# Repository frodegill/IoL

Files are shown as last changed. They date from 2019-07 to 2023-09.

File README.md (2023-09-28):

# IoL
Internet Of Låve (english: Internet Of Barn, a play on the term Internet Of Things) is a system I've made for a colleague at Computas that also happens to have a farm.  
The systems consists of a Raspberry Pi server, a WiFi access point for local WiFi and a set of ESP8266 with custom shield reporting sensor values using MQTT over WiFi.  

The custom shield is used for these tasks:
* Outdoor temperature and humidity
* Indoor temperature and humidity
* Air duct temperature, humidity, air speed and air pressure
* Two temperature and humidity sensors to put into the grain

The goal of this project is to calculate when outside air blown indoors is drier than the air that is already indoor, and thus starting a fan running on cheap electricity would be enough to dry the grain instead of having the air dryer running on expensive diesel.

### pictures

Here is a picture of the barn full of grain. The air duct comes down from the ceiling and under the left side window. There are air vents crossing the room running from the left side air duct.  
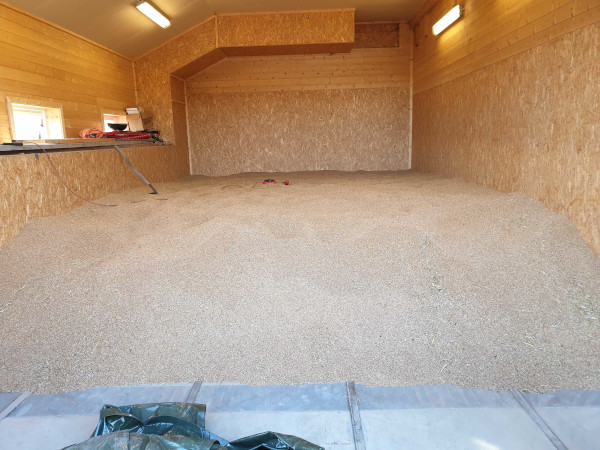
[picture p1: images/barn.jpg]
The barn full of grain
  

All sensor values are sent by MQTT to Mosquitto running on the Raspberry Pi. A local installation of Node-Red captures the values, massages them, and stores them in InfluxDB. A Grafana dashboard fetches data from InfluxDB and makes informative graphs. In the screenshot below you can see the period where the fan was manually turned on (thus creating wind speed and pressure difference in the air duct). This was immediately after the grain was harvested, so the results are admittedly better than usual, but you can see that the temperature and humidity in the grain will trend towards that in the air duct. As the outside humidity adjusted for indoor temperature is higher than the indoor humidity at the time of the screenshot, running the fan does not result in dryer grain and was only done for demonstration purposes.  
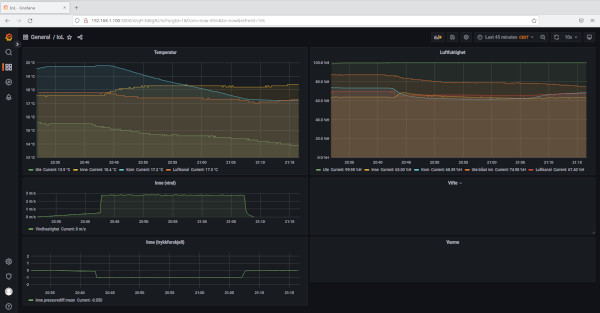
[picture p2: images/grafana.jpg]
Grafana dashboard


The barn does not have an internet connection, but the WiFi access point exposes Grafana running on the Raspberry Pi, and accessing it from a phone connected to the same WiFi network works like a charm.  
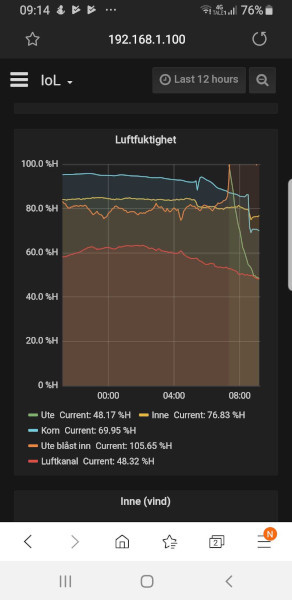
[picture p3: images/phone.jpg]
Grafana on small screen device


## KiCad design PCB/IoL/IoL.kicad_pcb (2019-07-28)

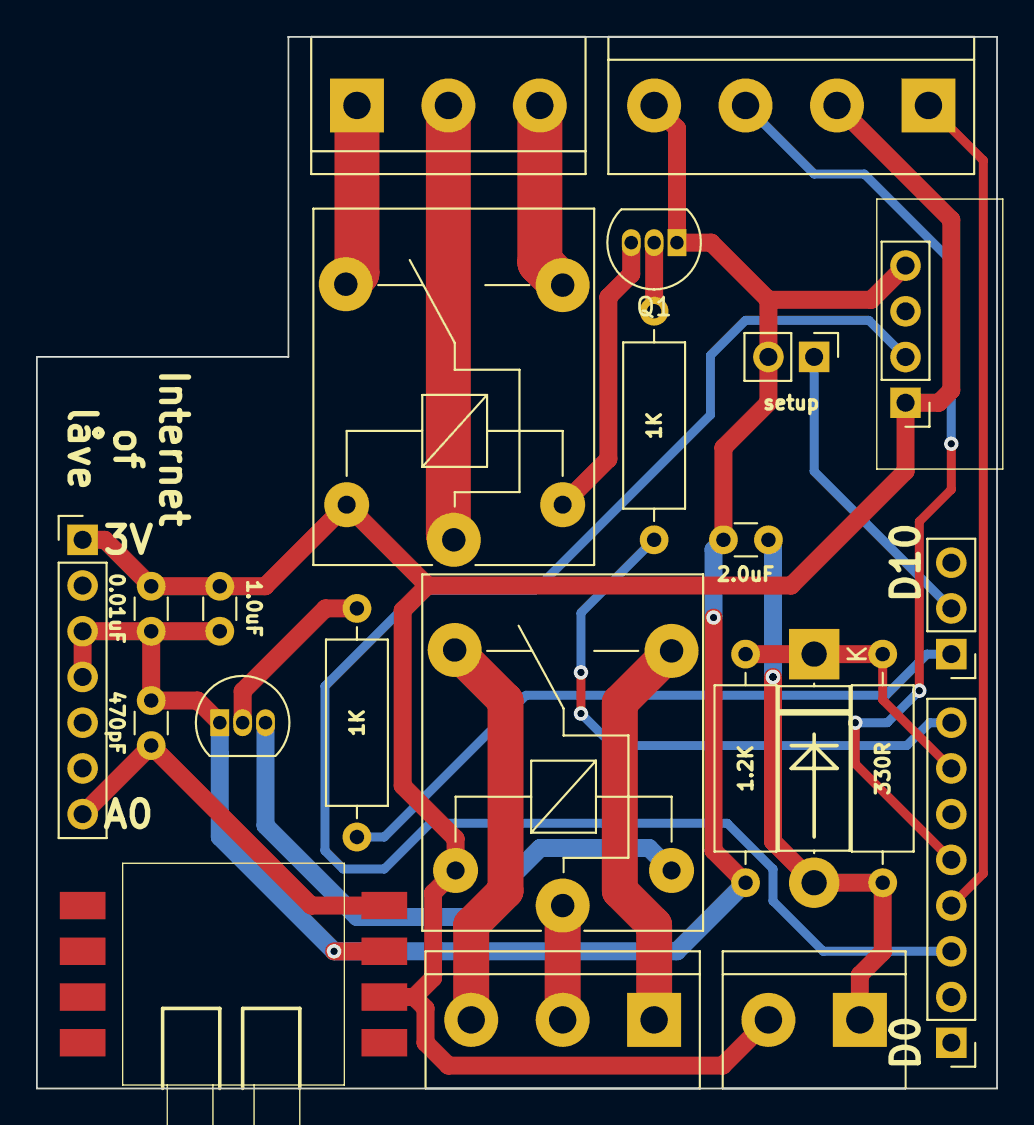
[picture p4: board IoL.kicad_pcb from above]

Board: 2 copper layers, 53.3 x 58.4 mm, 23 parts (0 on the bottom side), 21 nets.

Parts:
C1: 470pF; C_Disc_D3.0mm_W1.6mm_P2.50mm
C2: 1.0uF; C_Disc_D3.0mm_W1.6mm_P2.50mm
C3: 0.01uF; C_Disc_D3.0mm_W1.6mm_P2.50mm
C4: 2.0uF; C_Disc_D3.0mm_W1.6mm_P2.50mm
D1: D; D_5W_P12.70mm_Horizontal
J1, J9: Conn_01x03_Male; TerminalBlock_bornier-3_P5.08mm
J2: Conn_01x07_Male; PinHeader_1x07_P2.54mm_Vertical
J3: Conn_01x04_Male; TerminalBlock_bornier-4_P5.08mm
J5: Conn_01x02_Male; TerminalBlock_bornier-2_P5.08mm
J6: Conn_01x02_Male; PinHeader_1x02_P2.54mm_Vertical
J7: Conn_01x03_Male; PinHeader_1x03_P2.54mm_Vertical
J8: Conn_01x08_Male; PinHeader_1x08_P2.54mm_Vertical
K1, K2: SANYOU_SRD_Form_C; Relay_SPDT_SANYOU_SRD_Series_Form_C
Q1, Q2: BC337; TO-92_Inline
R1: 1.2K; R_Axial_DIN0309_L9.0mm_D3.2mm_P12.70mm_Horizontal
R2: 330R; R_Axial_DIN0309_L9.0mm_D3.2mm_P12.70mm_Horizontal
R3, R4: 1K; R_Axial_DIN0309_L9.0mm_D3.2mm_P12.70mm_Horizontal
U1: MP3V5004G
U2: AM2302

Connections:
+3V3: C2.1, C3.1, J2.1, J3.2, J5.2, K1.5, K2.5, U1.2, U2.1
GND: C1.2, C2.2, C3.2, C4.2, J2.3, J2.4, J3.4, J6.2, Q1.1, Q2.1, R1.2, U1.3, U2.4
unnamed: C1.1, J2.7, U1.4
unnamed: C4.1, D1.2, J5.1, R2.2
unnamed: D1.1, J8.7, R1.1, R2.1
unnamed: J1.1, K1.4
unnamed: J1.2, K1.1
unnamed: J1.3, K1.3
unnamed: J3.1, J8.4
unnamed: J3.3, J8.5
unnamed: J6.1, J7.2
unnamed: J7.1, R3.1
unnamed: J8.3, U2.2
unnamed: J8.8, R4.1
unnamed: J9.1, K2.3
unnamed: J9.2, K2.1
unnamed: J9.3, K2.4
unnamed: K1.2, Q1.3
unnamed: K2.2, Q2.3
unnamed: Q1.2, R4.2
unnamed: Q2.2, R3.2

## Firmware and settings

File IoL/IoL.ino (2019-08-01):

/*
 * Internet Of Låve
 * 
 * Measure and display Temperature and Humidity (AM2302 DHT22) and Wind Speed (MPXV7002DP), 
 * and provide these values to a Munin plugin.
 * 
 * Running on a WeMos D1 WiFi board.
 */

#include <DHTesp.h>
#include <DNSServer.h>
#include <EEPROM.h>
#include <ESP8266WiFi.h>
#include <ESP8266WebServer.h>
#include <PubSubClient.h>
#include "SHT21.h"
#include <Ticker.h>

static const char* SETUP_SSID = "sensor-setup";
static const byte  EEPROM_INITIALIZED_MARKER = 0xF1; //Just a magic number

static const uint8_t DHT_TEMP_HUMIDITY_SENSOR         = 1<<0;
static const uint8_t SHT_TEMP_HUMIDITY_SENSOR         = 1<<1;
static const uint8_t PRESSURE_DIFF_SENSOR             = 1<<2;
static const uint8_t WINDSPEED_SENSOR                 = 1<<3;
static const uint8_t FAN_RELAY                        = 1<<4;
static const uint8_t THERMOSTAT_RELAY                 = 1<<5;


#define I_PRESSURE_DIFF_PIN            (A0) //Max 3.3V

#define O_SHT_SYNC_PIN                 (D3) //SCL
#define I_SHT_DATA_PIN                 (D4) //SDA
#define I_DHT_PIN                      (D2)
#define I_SETUP_MODE_PIN               (D9) //built-in LED
#define I_WINDSPEED_PIN                (D6)
#define O_FAN_RELAY_TRIGGER_PIN        (D7)
#define O_THERMOSTAT_RELAY_TRIGGER_PIN (D8)

#define DELAY_BETWEEN_ACTIVE_SENSORS   (25) //ms between reading different sensors
#define SENSOR_READ_DELAY_TIME         (10*1000)  //ms min. time between sensor reading cycle
#define MQTT_PUBLISH_INTERVAL          (5*1000) //ms min. time between publishing sensor values to MQTT server

static const float WINDSPEED_TRAVEL_DISTANCE = 0.2262; //meter pr rotation

#define DHT_MODEL (DHTesp::AM2302)


enum DEBUG_MODE
{
  DEBUG_NONE,
  DEBUG_SERIAL,
  DEBUG_MQTT
} debug_mode = DEBUG_SERIAL;
#define MQTT_DEBUG_TOPIC "debug"

enum State
{
  SETUP_MODE,
  READ_DHT_SENSOR,
  READ_SHT_SENSOR,
  READ_PRESSURE_DIFF_SENSOR
};


DHTesp dht;
SHT21 sht;

ESP8266WebServer server(80);

WiFiClient esp_client;
PubSubClient mqtt_client(esp_client);
long last_mqtt_publish_time = 0L;

//For SETUP_SSID AP
DNSServer dnsServer;
static const byte DNS_PORT = 53;
IPAddress apIP(192, 168, 4, 1);

Ticker ticker;

volatile State state;

#define MAX_SSID_LENGTH            (32)
#define MAX_PASSWORD_LENGTH        (64)
#define MAX_ACTIVE_SENSORS_LENGTH   (1)
#define MAX_MQTT_SERVERNAME_LENGTH (64)
#define MAX_MQTT_SENSORID_LENGTH    (8)
#define MAX_MQTT_USERNAME_LENGTH   (32)
#define MAX_MQTT_PASSWORD_LENGTH   (32)

char ssid_param[MAX_SSID_LENGTH+1];
char password_param[MAX_PASSWORD_LENGTH+1];
char mqtt_servername_param[MAX_MQTT_SERVERNAME_LENGTH+1];
char mqtt_sensorid_param[MAX_MQTT_SENSORID_LENGTH+1];
char mqtt_username_param[MAX_MQTT_USERNAME_LENGTH+1];
char mqtt_password_param[MAX_MQTT_PASSWORD_LENGTH+1];
bool mqtt_enabled;
uint8_t active_sensors_param = 0;

volatile bool should_read_dht_temp_sensor = false;
float dht_tempsensor_value, published_dht_tempsensor_value;
float dht_humiditysensor_value, published_dht_humiditysensor_value;

volatile bool should_read_sht_temp_sensor = false;
float sht_tempsensor_value, published_sht_tempsensor_value;
float sht_humiditysensor_value, published_sht_humiditysensor_value;

volatile float pressure_diff_value, published_pressure_diff_value = -999.9f;

volatile unsigned long windspeed_start_time;
volatile unsigned int windspeed_count;
float published_windspeed = -999.9f;

volatile bool debug_enabled = false; // Internal, to keep track of Serial status

//Forward define
bool connectMQTT();


void enableDebug()
{
  if (!debug_enabled)
  {
    debug_enabled = true;
    if (debug_mode==DEBUG_SERIAL)
    {
      Serial.begin(9600);
    }
  }
}

void disableDebug()
{
  if (debug_enabled)
  {
    debug_enabled = false;
    if (debug_mode==DEBUG_SERIAL)
    {
      Serial.flush();
      Serial.end();
    }
  }
}

void printDebug(const char* msg)
{
  if (debug_enabled && msg)
  {
    if (debug_mode==DEBUG_SERIAL)
    {
      Serial.println(msg);
    }
    else if (debug_mode==DEBUG_MQTT && mqtt_enabled)
    {
      if (connectMQTT())
      {
        Serial.println((String("MQTT publish returned ") + String(mqtt_client.publish((String(mqtt_sensorid_param)+F(MQTT_DEBUG_TOPIC)).c_str(), msg)?"true":"false")).c_str());
      }
      else
      {
        Serial.println("Debug failed - MQTT is not connected");
      }
    }
  }
}

void ICACHE_RAM_ATTR windspeedInterruptHandler()
{
  if (0 == windspeed_count)
  {
    windspeed_start_time = millis();
  }
  windspeed_count++;
}

float getWindspeed() // m/s
{
  if (0 == windspeed_count)
  {
    return 0.0f;
  }

  unsigned long current_time = millis();
  if (current_time < windspeed_start_time)
  {
    return 0.0f;
  }

  float windspeed = (windspeed_count*WINDSPEED_TRAVEL_DISTANCE) / (current_time-windspeed_start_time); // meter/ms
  windspeed_count = 0;
  return windspeed*1000.0f; // meter/s
}

void onTick()
{
  switch(state)
  {
    case READ_DHT_SENSOR:
      {
        if (active_sensors_param & DHT_TEMP_HUMIDITY_SENSOR)
        {
          should_read_dht_temp_sensor = true;
        }

        state = READ_SHT_SENSOR;
        ticker.attach_ms(DELAY_BETWEEN_ACTIVE_SENSORS, onTick);
        break;  
      }

    case READ_SHT_SENSOR:
      {
        if (active_sensors_param & SHT_TEMP_HUMIDITY_SENSOR)
        {
          should_read_sht_temp_sensor = true;
        }
        
        state = READ_PRESSURE_DIFF_SENSOR;
        ticker.attach_ms(DELAY_BETWEEN_ACTIVE_SENSORS, onTick);
        break;
      }
    
    case READ_PRESSURE_DIFF_SENSOR:
      {
        if (active_sensors_param & PRESSURE_DIFF_SENSOR)
        {
          pressure_diff_value = max(0, min(1023, analogRead(I_PRESSURE_DIFF_PIN))) * 5.0f / 1023.0f -2.5f;
          printDebug((String("reading pressure diff value ")+String(pressure_diff_value, 2)).c_str());
        }
        
        state = READ_DHT_SENSOR;
        ticker.attach_ms(SENSOR_READ_DELAY_TIME, onTick);
        break;
      }
    
    default: break;
  }
}

void readPersistentString(char* s, int max_length, int& adr)
{
  int i = 0;
  byte c;
  do
  {
    c = EEPROM.read(adr++);
    if (i<max_length)
    {
      s[i++] = static_cast<char>(c);
    }
  } while (c!=0);
  s[i] = 0;
}

void readPersistentByte(uint8_t& b, int& adr)
{
  b = EEPROM.read(adr++);
}

void readPersistentParams()
{
  int adr = 0;
  if (EEPROM_INITIALIZED_MARKER != EEPROM.read(adr++))
  {
    ssid_param[0] = 0;
    password_param[0] = 0;
    mqtt_servername_param[0] = 0;
    mqtt_sensorid_param[0] = 0;
    mqtt_username_param[0] = 0;
    mqtt_password_param[0] = 0;
    active_sensors_param = 0;
  }
  else
  {
    readPersistentString(ssid_param, MAX_SSID_LENGTH, adr);
    readPersistentString(password_param, MAX_PASSWORD_LENGTH, adr);
    readPersistentByte(active_sensors_param, adr);
    readPersistentString(mqtt_servername_param, MAX_MQTT_SERVERNAME_LENGTH, adr);
    readPersistentString(mqtt_sensorid_param, MAX_MQTT_SENSORID_LENGTH, adr);
    readPersistentString(mqtt_username_param, MAX_MQTT_USERNAME_LENGTH, adr);
    readPersistentString(mqtt_password_param, MAX_MQTT_PASSWORD_LENGTH, adr);
  }
}

void writePersistentString(const char* s, size_t max_length, int& adr)
{
  for (int i=0; i<min(strlen(s), max_length); i++)
  {
    EEPROM.write(adr++, s[i]);
  }
  EEPROM.write(adr++, 0);
}

void writePersistentByte(uint8_t b, int& adr)
{
  EEPROM.write(adr++, b);
}

void writePersistentParams(const char* ssid, const char* password, uint8_t active_sensors)
{
  int adr = 0;
  EEPROM.write(adr++, EEPROM_INITIALIZED_MARKER);
  writePersistentString(ssid, MAX_SSID_LENGTH, adr);
  writePersistentString(password, MAX_PASSWORD_LENGTH, adr);
  writePersistentByte(active_sensors, adr);
  writePersistentString(mqtt_servername_param, MAX_MQTT_SERVERNAME_LENGTH, adr);
  writePersistentString(mqtt_sensorid_param, MAX_MQTT_SENSORID_LENGTH, adr);
  writePersistentString(mqtt_username_param, MAX_MQTT_USERNAME_LENGTH, adr);
  writePersistentString(mqtt_password_param, MAX_MQTT_PASSWORD_LENGTH, adr);
  EEPROM.commit();
}

void activateHeater(bool activate)
{
  if (active_sensors_param & THERMOSTAT_RELAY)
  {
    digitalWrite(O_THERMOSTAT_RELAY_TRIGGER_PIN, activate ? HIGH : LOW);
  }
}

void activateFan(bool activate)
{
  if (active_sensors_param & FAN_RELAY)
  {
    digitalWrite(O_FAN_RELAY_TRIGGER_PIN, activate ? HIGH : LOW);
  }
}

void handleNotFound()
{
  server.send(404, F("text/plain"), F("Page Not Found\n"));
}

void handleSetupRoot()
{
  if (server.hasArg("ssid") || server.hasArg("password")
      || server.hasArg("mqtt_server") || server.hasArg("mqtt_id") || server.hasArg("mqtt_username") || server.hasArg("mqtt_password")
      || server.hasArg("sensor0") || server.hasArg("sensor1") || server.hasArg("sensor2") || server.hasArg("sensor3")
      || server.hasArg("sensor4") || server.hasArg("sensor5") || server.hasArg("sensor6") || server.hasArg("sensor7"))
  {
    if (server.hasArg("ssid"))
    {
      strncpy(ssid_param, server.arg("ssid").c_str(), MAX_SSID_LENGTH);
      ssid_param[MAX_SSID_LENGTH] = 0;
    }
    
    if (server.hasArg("password") && !server.arg("password").equals(F("password")))
    {
      strncpy(password_param, server.arg("password").c_str(), MAX_PASSWORD_LENGTH);
      password_param[MAX_PASSWORD_LENGTH] = 0;
    }

    if (server.hasArg("mqtt_server"))
    {
      strncpy(mqtt_servername_param, server.arg("mqtt_server").c_str(), MAX_MQTT_SERVERNAME_LENGTH);
      mqtt_servername_param[MAX_MQTT_SERVERNAME_LENGTH] = 0;
    }
    if (server.hasArg("mqtt_id"))
    {
      strncpy(mqtt_sensorid_param, server.arg("mqtt_id").c_str(), MAX_MQTT_SENSORID_LENGTH);
      mqtt_sensorid_param[MAX_MQTT_SENSORID_LENGTH] = 0;
    }
    if (server.hasArg("mqtt_username"))
    {
      strncpy(mqtt_username_param, server.arg("mqtt_username").c_str(), MAX_MQTT_USERNAME_LENGTH);
      mqtt_username_param[MAX_MQTT_USERNAME_LENGTH] = 0;
    }
    if (server.hasArg("mqtt_password") && !server.arg("mqtt_password").equals(F("mqtt_password")))
    {
      strncpy(mqtt_password_param, server.arg("mqtt_password").c_str(), MAX_MQTT_PASSWORD_LENGTH);
      mqtt_password_param[MAX_MQTT_PASSWORD_LENGTH] = 0;
    }

    active_sensors_param = 0;
    if (server.hasArg("sensor0")) {active_sensors_param |= 1<<0;}
    if (server.hasArg("sensor1")) {active_sensors_param |= 1<<1;}
    if (server.hasArg("sensor2")) {active_sensors_param |= 1<<2;}
    if (server.hasArg("sensor3")) {active_sensors_param |= 1<<3;}
    if (server.hasArg("sensor4")) {active_sensors_param |= 1<<4;}
    if (server.hasArg("sensor5")) {active_sensors_param |= 1<<5;}
    if (server.hasArg("sensor6")) {active_sensors_param |= 1<<6;}
    if (server.hasArg("sensor7")) {active_sensors_param |= 1<<7;}

    writePersistentParams(ssid_param, password_param, active_sensors_param);

    server.send(200, F("text/plain"), F("Settings saved"));
  }
  else
  {
    readPersistentParams();

    String body = F("<!doctype html>"\
                    "<html lang=\"en\">"\
                    "<head>"\
                     "<meta charset=\"utf-8\">"\
                     "<title>Setup</title>"\
                     "<style>"\
                      "form {margin: 0.5em;}"\
                      "input {margin: 0.2em;}"\
                     "</style>"\
                    "</head>"\
                    "<body>"\
                     "<form method=\"post\">"\
                      "SSID:<input type=\"text\" name=\"ssid\" required maxlength=\"");
    body += String(MAX_SSID_LENGTH);
    body += F("\" autofocus value=\"");
    body += ssid_param;
    body += F("\"/><br/>"\
              "Password:<input type=\"password\" name=\"password\" maxlength=\"");
    body += String(MAX_PASSWORD_LENGTH);
    body += F("\" value=\"password\"/><br/><hr/>"\
              "MQTT server:<input type=\"text\" name=\"mqtt_server\" maxlength=\"");
    body += String(MAX_MQTT_SERVERNAME_LENGTH);
    body += F("\" value=\"");
    body += mqtt_servername_param;
    body += F("\"/><br/>"\
              "MQTT sensor id:<input type=\"text\" name=\"mqtt_id\" maxlength=\"");
    body += String(MAX_MQTT_SENSORID_LENGTH);
    body += F("\" value=\"");
    body += mqtt_sensorid_param;
    body += F("\"/><br/>"\
              "MQTT username:<input type=\"text\" name=\"mqtt_username\" maxlength=\"");
    body += String(MAX_MQTT_USERNAME_LENGTH);
    body += F("\" value=\"");
    body += mqtt_username_param;
    body += F("\"/><br/>"\
              "MQTT password:<input type=\"password\" name=\"mqtt_password\" maxlength=\"");
    body += String(MAX_MQTT_PASSWORD_LENGTH);
    body += F("\" value=\"password\"/><br/><hr/>"\
              "Internal temp/humidity sensor: <input type=\"checkbox\" name=\"sensor0\"");
    if (active_sensors_param&DHT_TEMP_HUMIDITY_SENSOR)
      body += F(" checked");

    body += F("/><br/>External temp sensor: <input type=\"checkbox\" name=\"sensor1\"");
    if (active_sensors_param&SHT_TEMP_HUMIDITY_SENSOR)
      body += F(" checked");
    
    body += F("/><br/>Pressure diff. sensor: <input type=\"checkbox\" name=\"sensor2\"");
    if (active_sensors_param&PRESSURE_DIFF_SENSOR)
      body += F(" checked");
    
    body += F("/><br/>Windspeed sensor: <input type=\"checkbox\" name=\"sensor3\"");
    if (active_sensors_param&WINDSPEED_SENSOR)
      body += F(" checked");
    
    body += F("/><br/>Fan relay: <input type=\"checkbox\" name=\"sensor4\"");
    if (active_sensors_param&FAN_RELAY)
      body += F(" checked");
    
    body += F("/><br/>Heater thermostat plug: <input type=\"checkbox\" name=\"sensor5\"");
    if (active_sensors_param&THERMOSTAT_RELAY)
      body += F(" checked");
    
    body += F("/><br/>"\
              "<input type=\"submit\" value=\"Submit\"/>"\
              "</form>"\
             "</body>"\
             "</html>");
    server.send(200, F("text/html"), body);
  }
}

void mqttCallback(char* topic, byte* payload, unsigned int length)
{
  int mqtt_sensorid_param_length = strlen(mqtt_sensorid_param);
  if (0 != strncmp(mqtt_sensorid_param, topic, mqtt_sensorid_param_length))
  {
    return;
  }

  printDebug((String("mqttCallback: ")+String(topic)+String(" value ")+String(reinterpret_cast<const char*>(payload))).c_str());
  const char* key = topic + mqtt_sensorid_param_length;

  if (0 == strcmp("Heater", key))
  {
    activateHeater(0 == strcmp("on", reinterpret_cast<const char*>(payload)));
  }
  else if (0 == strcmp("Fan", key))
  {
    activateFan(0 == strcmp("on", reinterpret_cast<const char*>(payload)));
  }
}

void publishMQTTValue(const String& topic, const String& msg)
{
  if (mqtt_enabled && connectMQTT())
  {
    bool ret = mqtt_client.publish((String(mqtt_sensorid_param)+topic).c_str(), msg.c_str(), true);
    printDebug((String("publishMQTTValue topic=")+String(mqtt_sensorid_param)+topic+String(" msg=")+msg+String(" returned ")+String(ret?"true":"false")).c_str());
  }
}

void publishMQTTValue(const String& topic, float value)
{
  publishMQTTValue(topic, String(value, 4));
}

void publishMQTTValues()
{
  if (!mqtt_enabled)
    return;

  if (active_sensors_param&DHT_TEMP_HUMIDITY_SENSOR)
  {
    if (dht_tempsensor_value!=published_dht_tempsensor_value)
    {
      publishMQTTValue(F("DHT22T"), dht_tempsensor_value);
      published_dht_tempsensor_value = dht_tempsensor_value;
    }
    if (dht_humiditysensor_value!=published_dht_humiditysensor_value)
    {
      publishMQTTValue(F("DHT22H"), dht_humiditysensor_value);
      published_dht_humiditysensor_value = dht_humiditysensor_value;
    }
  }

  if (active_sensors_param&SHT_TEMP_HUMIDITY_SENSOR)
  {
    if (sht_tempsensor_value!=published_sht_tempsensor_value)
    {
      publishMQTTValue(F("SHT2XT"), sht_tempsensor_value);
      published_sht_tempsensor_value = sht_tempsensor_value;
    }
    if (sht_humiditysensor_value!=published_sht_humiditysensor_value)
    {
      publishMQTTValue(F("SHT2XH"), sht_humiditysensor_value);
      published_sht_humiditysensor_value = sht_humiditysensor_value;
    }
  }

  if (active_sensors_param&PRESSURE_DIFF_SENSOR)
  {
    if (pressure_diff_value!=published_pressure_diff_value)
    {
      publishMQTTValue(F("Pressure"), pressure_diff_value);
      published_pressure_diff_value = pressure_diff_value;
    }
  }
  
  if (active_sensors_param&WINDSPEED_SENSOR)
  {
    float windspeed = getWindspeed();
    printDebug((String("reading wind speed value ")+String(windspeed, 2)).c_str());
    if (windspeed!=published_windspeed)
    {
      publishMQTTValue(F("Wind"), windspeed);
      published_windspeed = windspeed;
    }
  }
}

bool connectMQTT()
{
  byte i = 0;
  while (i++<10 && mqtt_enabled && !mqtt_client.connected())
  {
    if (mqtt_client.connect(mqtt_sensorid_param, mqtt_username_param, mqtt_password_param))
    {
      printDebug("MQTT connected");

      if (active_sensors_param & THERMOSTAT_RELAY)
      {
        mqtt_client.subscribe((String(mqtt_sensorid_param)+F("Heater")).c_str());
      }
      
      if (active_sensors_param & FAN_RELAY)
      {
        mqtt_client.subscribe((String(mqtt_sensorid_param)+F("Fan")).c_str());
      }
      
      printDebug("MQTT topics subscribed");
    }
    else
    {
      printDebug("MQTT waiting for reconnect");
      // Wait 3 seconds before retrying
      delay(3000);
    }
  }
  return mqtt_client.connected();
}

void setup()
{
  enableDebug();

  EEPROM.begin(1 + MAX_SSID_LENGTH+1 + MAX_PASSWORD_LENGTH+1 + MAX_ACTIVE_SENSORS_LENGTH + MAX_MQTT_SERVERNAME_LENGTH+1 + MAX_MQTT_SENSORID_LENGTH+1 + MAX_MQTT_USERNAME_LENGTH+1 + MAX_MQTT_PASSWORD_LENGTH+1);

  pinMode(I_SETUP_MODE_PIN, INPUT_PULLUP);
  delay(100);

  if (/*true ||*/ LOW == digitalRead(I_SETUP_MODE_PIN))
  {
    printDebug("Mode:Setup");

    mqtt_enabled = false;
    state = SETUP_MODE;
    WiFi.softAP(SETUP_SSID);
    dnsServer.start(DNS_PORT, "*", apIP);

    server.on("/", handleSetupRoot);
    server.onNotFound(handleNotFound);
    server.begin();
  }
  else
  {
    printDebug("Mode:Normal");

    dht.setup(I_DHT_PIN, DHTesp::AM2302);
    sht.begin(/*I_SHT_DATA_PIN, O_SHT_SYNC_PIN*/);

    pinMode(O_FAN_RELAY_TRIGGER_PIN, OUTPUT);
    activateFan(false);

    pinMode(O_THERMOSTAT_RELAY_TRIGGER_PIN, OUTPUT);
    activateHeater(false);

    readPersistentParams();
    mqtt_enabled = mqtt_servername_param && *mqtt_servername_param;
    
    printDebug("Connecting to WiFi");
    WiFi.mode(WIFI_STA);
    WiFi.begin(ssid_param, password_param);
    while (WiFi.status() != WL_CONNECTED)
    {
      delay(500);
    }
    printDebug("WiFi connected");

    if (mqtt_enabled)
    {
      printDebug("Enabling MQTT");
      mqtt_client.setServer(mqtt_servername_param, 1883);
      mqtt_client.setCallback(mqttCallback);
      connectMQTT();
    }

    should_read_dht_temp_sensor = false;
    dht_tempsensor_value = dht_humiditysensor_value = 0.0f;

    should_read_sht_temp_sensor = false;
    sht_tempsensor_value = 0.0f;
    sht_humiditysensor_value = 0.0f;
    pressure_diff_value = 0.0f;

    state = READ_DHT_SENSOR;
    onTick();

    if (active_sensors_param && WINDSPEED_SENSOR)
    {
      windspeed_start_time = 0;
      windspeed_count = 0;
      attachInterrupt(digitalPinToInterrupt(I_WINDSPEED_PIN), windspeedInterruptHandler, RISING);
    }

    //Notify MQTT that relays have been turned off
    if (active_sensors_param & THERMOSTAT_RELAY)
    {
      publishMQTTValue("Heater", "off");
    }
    if (active_sensors_param & FAN_RELAY)
    {
      publishMQTTValue("Fan", "off");
    }
  }
}

void loop()
{
  if (state == SETUP_MODE)
  {
    dnsServer.processNextRequest(); //Route everything to 192.168.4.1
    server.handleClient(); //WebServer
  }
  else
  {
    if (mqtt_enabled && connectMQTT())
    {
      mqtt_client.loop();
    
      long now = millis();
      if ((now - last_mqtt_publish_time) > MQTT_PUBLISH_INTERVAL)
      {
        last_mqtt_publish_time = now;
        publishMQTTValues();
      }
    }

    //DHT22
    delay(max(1000, dht.getMinimumSamplingPeriod()));
    if ((active_sensors_param & DHT_TEMP_HUMIDITY_SENSOR) && should_read_dht_temp_sensor)
    {
      TempAndHumidity temp_and_humidity = dht.getTempAndHumidity();
      if (dht.getStatus() == DHTesp::ERROR_NONE)
      {
        should_read_dht_temp_sensor = false;
        dht_tempsensor_value = temp_and_humidity.temperature;
        dht_humiditysensor_value = temp_and_humidity.humidity;
        printDebug((String("reading temp ")+String(dht_tempsensor_value, 1)+String(" and humidity ")+String(dht_humiditysensor_value, 1)).c_str());
      }
      else
      {
        printDebug((String("reading temp and humidity failed with error ")+String((int)dht.getStatus())).c_str());
      }
    }
  
    //SHT2x
    if ((active_sensors_param & SHT_TEMP_HUMIDITY_SENSOR) && should_read_sht_temp_sensor)
    {
      sht_tempsensor_value = sht.getTemperature();
      sht_humiditysensor_value = sht.getHumidity();
      should_read_sht_temp_sensor = false;
    }
  }
}

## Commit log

2018-06-14 Replaced with empty sensor framework
    [IoL.ino]
2018-06-29 Windspeed sensor
2018-07-02 Use A and B instead of 1 and 2 for temp sensors
2018-08-14 Use only one I2C SHT precision temp sensor. And MQTT WIP
2019-07-28 Lots of small fixes :-/
    [IoL.ino]
2019-07-28 Added KiCAD files
    [IoL.kicad_pcb, IoL.sch]
2019-07-31 More pin renaming
2019-08-01 Let MQTT handle fan and heater
2019-08-18 Added Node-RED flow
